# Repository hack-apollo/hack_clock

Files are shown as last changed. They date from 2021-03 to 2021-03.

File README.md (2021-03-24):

HACK LABS MatrixClock : https://www.youtube.com/watch?v=k0h2WS6Prsc&t=33s                                                                                
Author: HACK实验室                                                                                     
YouTube ID: HACK实验室, welcome to subscribe https://www.youtube.com/c/HACK实验室                                                        
HACK_CLOCK is a free download and may be used, modified, evaluated and
distributed without charge provided the user adheres to version three of the GNU
General Public License (GPL) and does not remove the copyright notice or this
text.  The GPL V3 text is available on the gnu.org web site
作者：HACK实验室                                                                                        
B站ID：HACK实验室  欢迎订阅 https://space.bilibili.com/395145107                                                                            
微信公众号：HACK实验室，开源资料唯一发布点，定期分享开源硬件以及有价值的技术文章，欢迎关注.                                                                                                             

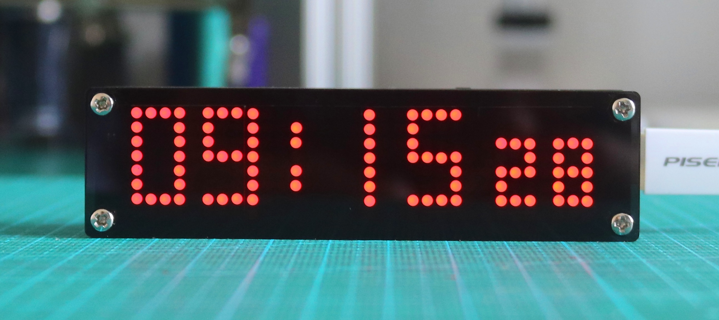
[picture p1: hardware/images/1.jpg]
Image text


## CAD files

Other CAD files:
hardware/滤光板/挡板1.dwg

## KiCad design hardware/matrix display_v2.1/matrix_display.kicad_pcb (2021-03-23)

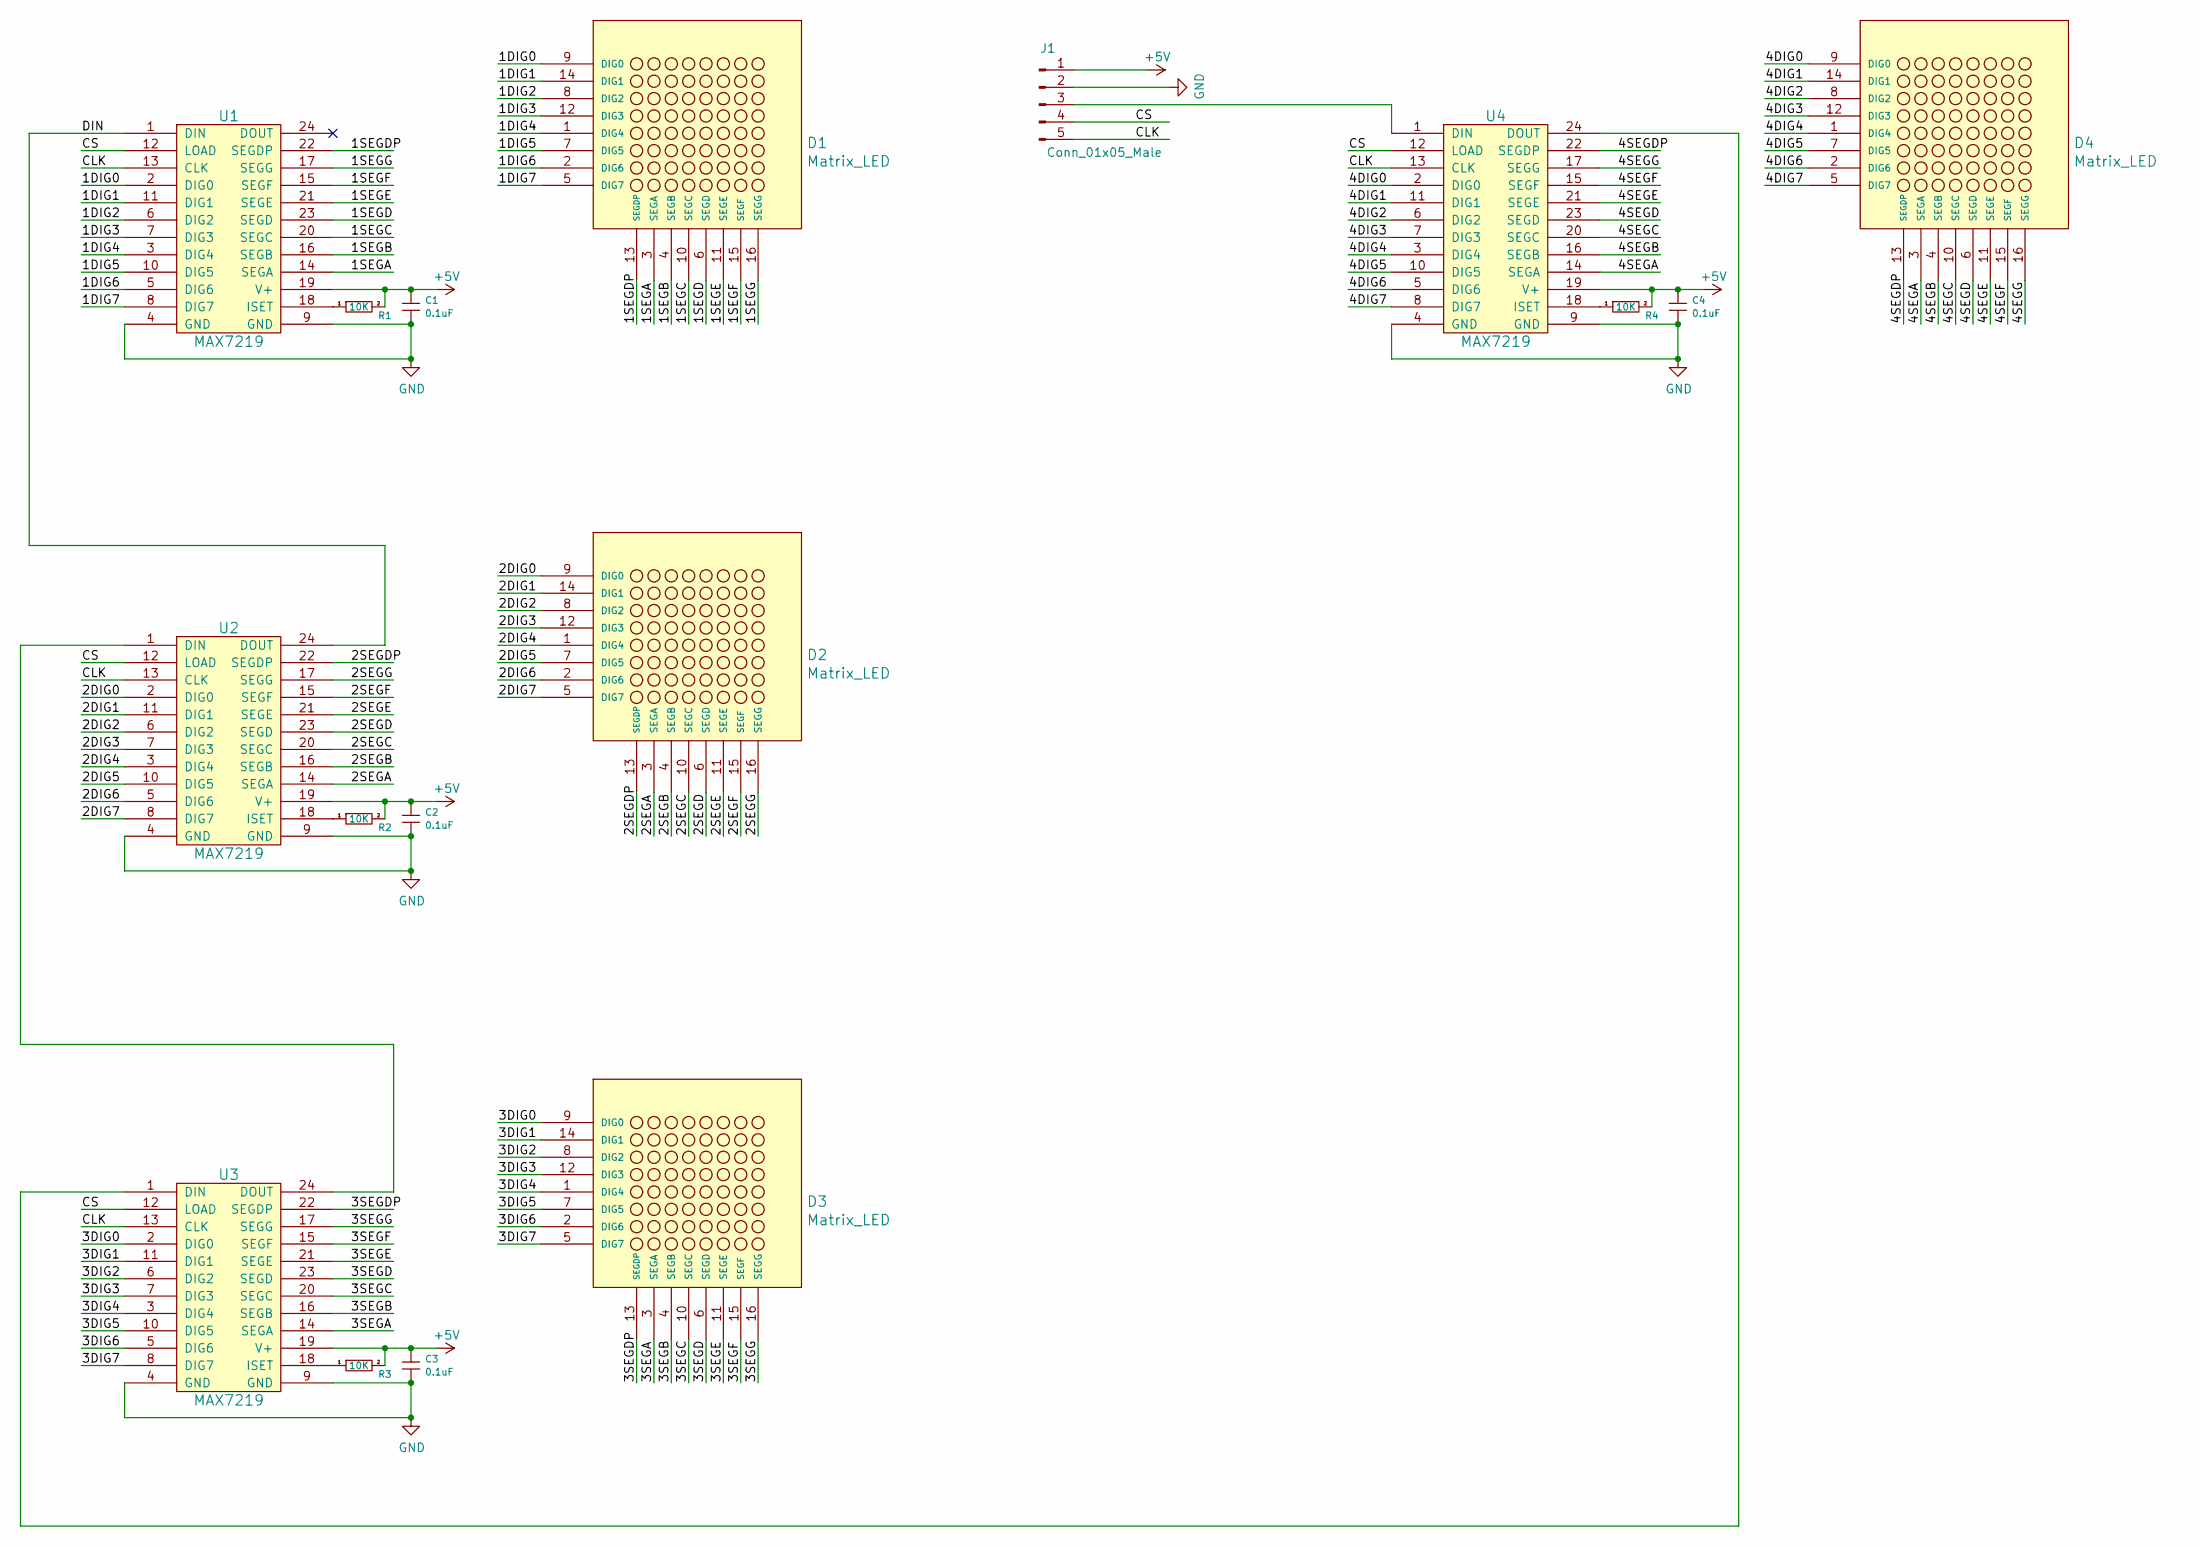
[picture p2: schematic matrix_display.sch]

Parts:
C1, C2, C3, C4: 0.1uF; 0603_C
D1, D2, D3, D4: Matrix_LED
J1: Conn_01x05_Male; PinHeader_1x05_P2.00mm_Vertical
R1, R2, R3, R4: 10K; 0603_R
U1, U2, U3, U4: MAX7219; SOIC-24W_7.5x15.4mm_P1.27mm

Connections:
+5V: C1.1, C2.1, C3.1, C4.1, J1.1, R1.2, R2.2, R3.2, R4.2, U1.19 (V+), U2.19 (V+), U3.19 (V+), U4.19 (V+)
/1DIG0: D1.9 (DIG0), U1.2 (DIG0)
/1DIG1: D1.14 (DIG1), U1.11 (DIG1)
/1DIG2: D1.8 (DIG2), U1.6 (DIG2)
/1DIG3: D1.12 (DIG3), U1.7 (DIG3)
/1DIG4: D1.1 (DIG4), U1.3 (DIG4)
/1DIG5: D1.7 (DIG5), U1.10 (DIG5)
/1DIG6: D1.2 (DIG6), U1.5 (DIG6)
/1DIG7: D1.5 (DIG7), U1.8 (DIG7)
/1SEGA: D1.3 (SEGA), U1.14 (SEGA)
/1SEGB: D1.4 (SEGB), U1.16 (SEGB)
/1SEGC: D1.10 (SEGC), U1.20 (SEGC)
/1SEGD: D1.6 (SEGD), U1.23 (SEGD)
/1SEGDP: D1.13 (SEGDP), U1.22 (SEGDP)
/1SEGE: D1.11 (SEGE), U1.21 (SEGE)
/1SEGF: D1.15 (SEGF), U1.15 (SEGF)
/1SEGG: D1.16 (SEGG), U1.17 (SEGG)
/2DIG0: D2.9 (DIG0), U2.2 (DIG0)
/2DIG1: D2.14 (DIG1), U2.11 (DIG1)
/2DIG2: D2.8 (DIG2), U2.6 (DIG2)
/2DIG3: D2.12 (DIG3), U2.7 (DIG3)
/2DIG4: D2.1 (DIG4), U2.3 (DIG4)
/2DIG5: D2.7 (DIG5), U2.10 (DIG5)
/2DIG6: D2.2 (DIG6), U2.5 (DIG6)
/2DIG7: D2.5 (DIG7), U2.8 (DIG7)
/2SEGA: D2.3 (SEGA), U2.14 (SEGA)
/2SEGB: D2.4 (SEGB), U2.16 (SEGB)
/2SEGC: D2.10 (SEGC), U2.20 (SEGC)
/2SEGD: D2.6 (SEGD), U2.23 (SEGD)
/2SEGDP: D2.13 (SEGDP), U2.22 (SEGDP)
/2SEGE: D2.11 (SEGE), U2.21 (SEGE)
/2SEGF: D2.15 (SEGF), U2.15 (SEGF)
/2SEGG: D2.16 (SEGG), U2.17 (SEGG)
/3DIG0: D3.9 (DIG0), U3.2 (DIG0)
/3DIG1: D3.14 (DIG1), U3.11 (DIG1)
/3DIG2: D3.8 (DIG2), U3.6 (DIG2)
/3DIG3: D3.12 (DIG3), U3.7 (DIG3)
/3DIG4: D3.1 (DIG4), U3.3 (DIG4)
/3DIG5: D3.7 (DIG5), U3.10 (DIG5)
/3DIG6: D3.2 (DIG6), U3.5 (DIG6)
/3DIG7: D3.5 (DIG7), U3.8 (DIG7)
/3SEGA: D3.3 (SEGA), U3.14 (SEGA)
/3SEGB: D3.4 (SEGB), U3.16 (SEGB)
/3SEGC: D3.10 (SEGC), U3.20 (SEGC)
/3SEGD: D3.6 (SEGD), U3.23 (SEGD)
/3SEGDP: D3.13 (SEGDP), U3.22 (SEGDP)
/3SEGE: D3.11 (SEGE), U3.21 (SEGE)
/3SEGF: D3.15 (SEGF), U3.15 (SEGF)
/3SEGG: D3.16 (SEGG), U3.17 (SEGG)
/4DIG0: D4.9 (DIG0), U4.2 (DIG0)
/4DIG1: D4.14 (DIG1), U4.11 (DIG1)
/4DIG2: D4.8 (DIG2), U4.6 (DIG2)
/4DIG3: D4.12 (DIG3), U4.7 (DIG3)
/4DIG4: D4.1 (DIG4), U4.3 (DIG4)
/4DIG5: D4.7 (DIG5), U4.10 (DIG5)
/4DIG6: D4.2 (DIG6), U4.5 (DIG6)
/4DIG7: D4.5 (DIG7), U4.8 (DIG7)
/4SEGA: D4.3 (SEGA), U4.14 (SEGA)
/4SEGB: D4.4 (SEGB), U4.16 (SEGB)
/4SEGC: D4.10 (SEGC), U4.20 (SEGC)
/4SEGD: D4.6 (SEGD), U4.23 (SEGD)
/4SEGDP: D4.13 (SEGDP), U4.22 (SEGDP)
/4SEGE: D4.11 (SEGE), U4.21 (SEGE)
/4SEGF: D4.15 (SEGF), U4.15 (SEGF)
/4SEGG: D4.16 (SEGG), U4.17 (SEGG)
/CLK: J1.5, U1.13 (CLK), U2.13 (CLK), U3.13 (CLK), U4.13 (CLK)
/CS: J1.4, U1.12 (LOAD), U2.12 (LOAD), U3.12 (LOAD), U4.12 (LOAD)
/DIN: U1.1 (DIN), U2.24 (DOUT)
GND: C1.2, C2.2, C3.2, C4.2, J1.2, U1.4 (GND), U1.9 (GND), U2.4 (GND), U2.9 (GND), U3.4 (GND), U3.9 (GND), U4.4 (GND), U4.9 (GND)
unnamed: J1.3, U4.1 (DIN)
unnamed: R1.1, U1.18 (ISET)
unnamed: R2.1, U2.18 (ISET)
unnamed: R3.1, U3.18 (ISET)
unnamed: R4.1, U4.18 (ISET)
unnamed: U2.1 (DIN), U3.24 (DOUT)
unnamed: U3.1 (DIN), U4.24 (DOUT)

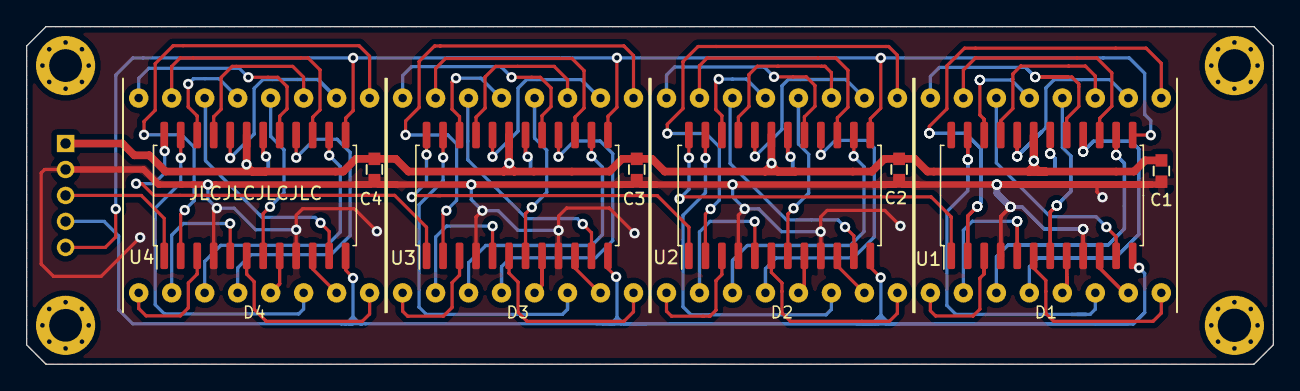
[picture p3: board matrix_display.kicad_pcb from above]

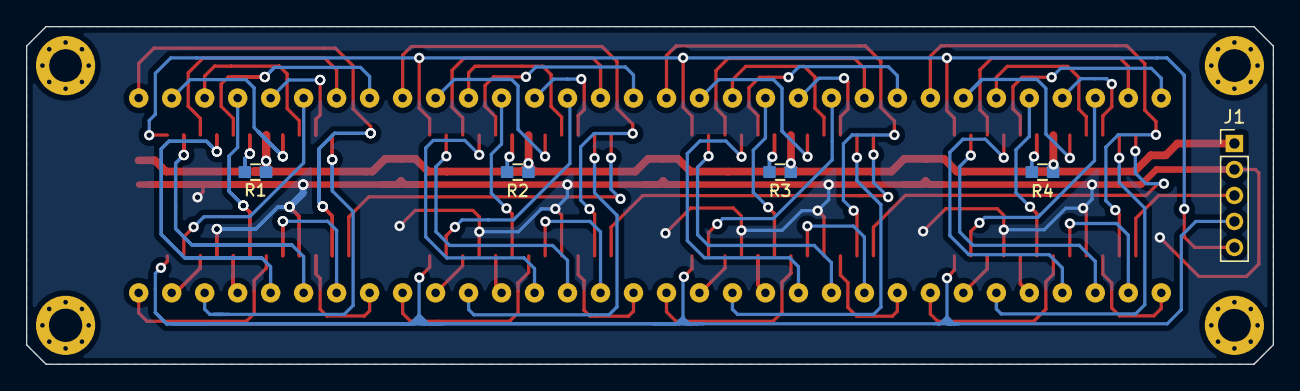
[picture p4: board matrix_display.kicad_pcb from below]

Board: 2 copper layers, 96.0 x 26.0 mm, 17 parts (5 on the bottom side), 76 nets.

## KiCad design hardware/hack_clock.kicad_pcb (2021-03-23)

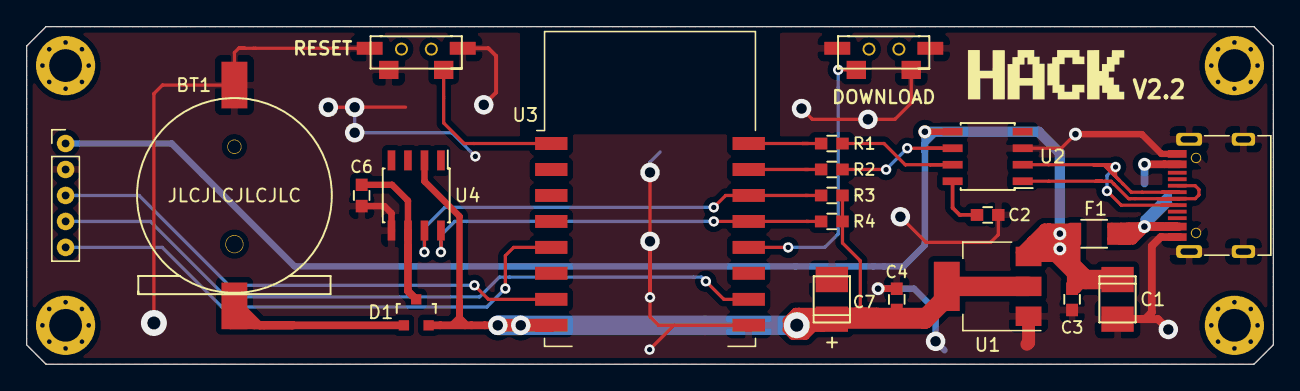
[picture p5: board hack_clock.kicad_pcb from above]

Board: 2 copper layers, 96.0 x 26.0 mm, 23 parts (1 on the bottom side), 20 nets.

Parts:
BT1: BATTERY(M); CR1220-SMD
C1, C7: 100uF; TantalC_SizeT_3528
C2, C6: 0.1uF; 0603_C
C3, C4: 1uF; 0603_C
D1: BAT54C; SOT-23
F1: FUSE*; F_1206
J1: Conn_01x05_Male; PinHeader_1x05_P2.00mm_Vertical
J2: Jack-DC; BarrelJack_DCDC-SMT
P3: USB_C_Plug_USB2.0; USB-Type-C-NEW
P665: CON_1; CON1
R1, R2: RES(M); 0603_R
R3, R4: 10K; 0603_R
SW1, SW2: switch; SWITCH_PUSH
U1: AMS1117; SOT-223-3_TabPin2
U2: CH340N; SOP-8
U3: ESP-12; ESP-12S
U4: DS3231MZ+; SOP-8

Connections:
+3V3: C4.2, C7.1, D1.2, R3.2, R4.2, U1.2, U3.8, U4.2
+5V: C1.1, C3.2, F1.2, J1.1, U1.3, U2.5
/CLK: J1.5, U3.5
/CS: J1.4, U3.16
/DIN: J1.3, U3.7
/RXD: R1.2, U3.22
/SCL: R4.1, U3.19, U4.8
/SDA: R3.1, U3.20, U4.7
/TXD: R2.2, U3.21
/USB_D+: P3.A6, U2.1
/USB_D-: P3.A7, U2.2
GND: BT1.2, C1.2, C2.1, C3.1, C4.1, C6.1, C7.2, J1.2, J2.2, P3.A1, P3.S1, SW1.1, SW2.1, U1.1, U2.3, U3.15, U4.5
unnamed: BT1.1, D1.1
unnamed: C2.2, U2.8
unnamed: C6.2, D1.3, U4.6
unnamed: F1.1, J2.1, P3.A4
unnamed: R1.1, U2.7
unnamed: R2.1, U2.6
unnamed: SW1.2, U3.1
unnamed: SW2.2, U3.18

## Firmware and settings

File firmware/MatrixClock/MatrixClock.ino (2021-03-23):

/*********************************************************************************************************
  HACK LABS MatrixClock                                                                                 
  ********************************************************************************************************
  Author: HACK实验室                                                                                     
  YouTube ID: HACK实验室, welcome to subscribe：https://www.youtube.com/channel/UCxFY1FcIYK9d7riTvIh6eiA                                                          
  Version 2.0 
  HACK_CLOCK is a free download and may be used, modified, evaluated and
  distributed without charge provided the user adheres to version hree of the GNU
  General Public License (GPL) and does not remove the copyright notice or this
  text.  The GPL V3 text is available on the gnu.org web site
  作者：HACK实验室                                                                                        
  B站ID：HACK实验室  欢迎订阅：https://space.bilibili.com/395145107                                                                             
  微信公众号：HACK实验室，开源资料唯一发布点，定期分享开源硬件以及有价值的技术文章，欢迎关注.                        
  Version 2.0                                                                                           
  HACK_CLOCK是一个完全开源的硬件项目，允许用户免费下载使用，但需遵守GPL V3开源协议，协议文本可在gnu.org网站上获得.    
*********************************************************************************************************/

#include <SPI.h>
#include <Ticker.h>
#include <ESP8266WiFi.h>
#include <WiFiClient.h>
#include <WiFiUdp.h>
#include <Wire.h>
#include <time.h>

#define SDA        5      // Pin sda (I2C)
#define SCL        4      // Pin scl (I2C)
#define CS         15     // Pin cs  (SPI)
#define anzMAX     4     


char ssid[] = "";                    // your network SSID (name)
char pass[] = "";                    // your network password

unsigned short maxPosX = anzMAX * 8 - 1;            
unsigned short LEDarr[anzMAX][8];                   
unsigned short helpArrMAX[anzMAX * 8];              
unsigned short helpArrPos[anzMAX * 8];              
unsigned int z_PosX = 0;                            
unsigned int d_PosX = 0;                            
bool f_tckr1s = false;
bool f_tckr50ms = false;
unsigned long epoch = 0;
unsigned int localPort = 2390;                      // local port to listen for UDP packets
const char* ntpServerName = "time1.aliyun.com";
const int NTP_PACKET_SIZE = 48;                     // NTP time stamp is in the first 48 bytes of the message
byte packetBuffer[NTP_PACKET_SIZE];                 // buffer to hold incoming and outgoing packets
IPAddress timeServerIP;                            
tm *tt, ttm;


const unsigned char DS3231_ADDRESS = 0x68;
const unsigned char secondREG = 0x00;
const unsigned char minuteREG = 0x01;
const unsigned char hourREG = 0x02;
const unsigned char WTREG = 0x03;                   //weekday
const unsigned char dateREG = 0x04;
const unsigned char monthREG = 0x05;
const unsigned char yearREG = 0x06;
const unsigned char alarm_min1secREG = 0x07;
const unsigned char alarm_min1minREG = 0x08;
const unsigned char alarm_min1hrREG = 0x09;
const unsigned char alarm_min1dateREG = 0x0A;
const unsigned char alarm_min2minREG = 0x0B;
const unsigned char alarm_min2hrREG = 0x0C;
const unsigned char alarm_min2dateREG = 0x0D;
const unsigned char controlREG = 0x0E;
const unsigned char statusREG = 0x0F;
const unsigned char ageoffsetREG = 0x10;
const unsigned char tempMSBREG = 0x11;
const unsigned char tempLSBREG = 0x12;
const unsigned char _24_hour_format = 0;
const unsigned char _12_hour_format = 1;
const unsigned char AM = 0;
const unsigned char PM = 1;

struct DateTime {
    unsigned short sek1, sek2, sek12, min1, min2, min12, std1, std2, std12;
    unsigned short tag1, tag2, tag12, mon1, mon2, mon12, jahr1, jahr2, jahr12, WT;
} MEZ;


// The object for the Ticker
Ticker tckr;
// A UDP instance to let us send and receive packets over UDP
WiFiUDP udp;


//months
char M_arr[12][5] = { { ' ', 'J', 'A', 'N', ' ' }, { ' ', 'F', 'E', 'B', ' ' },
        { ' ', 'M', 'A', 'R', ' ' }, { ' ', 'A', 'P', 'R', ' ' }, { ' ', 'M', 'A',
                'Y', ' ' }, { ' ', 'J', 'U', 'N', ' ' }, { ' ', 'J', 'U', 'L', ' ' }, {
                ' ', 'A', 'U', 'G', ' ' }, { ' ', 'S', 'E', 'P', ' ' }, { ' ', 'O', 'C',
                'T', ' ' }, { ' ', 'N', 'O', 'V', ' ' }, { ' ', 'D', 'E', 'C', ' ' } };
//days
char WT_arr[7][4] = { { 'S', 'U', 'N', ' ' }, { 'M', 'O', 'N', ' ' }, { 'T', 'U', 'E', ' ' }, {
        'W', 'E', 'D', ' ' }, { 'T', 'H', 'U', ' ' }, { 'F', 'R', 'I', ' ' }, { 'S', 'A', 'T', ' ' } };

// Zeichensatz 5x8 in einer 8x8 Matrix, 0,0 ist rechts oben
unsigned short const font1[96][9] = { { 0x07, 0x00, 0x00, 0x00, 0x00, 0x00,
        0x00, 0x00, 0x00 },   // 0x20, Space
        { 0x07, 0x04, 0x04, 0x04, 0x04, 0x04, 0x00, 0x04, 0x00 },   // 0x21, !
        { 0x07, 0x09, 0x09, 0x12, 0x00, 0x00, 0x00, 0x00, 0x00 },   // 0x22, "
        { 0x07, 0x0a, 0x0a, 0x1f, 0x0a, 0x1f, 0x0a, 0x0a, 0x00 },   // 0x23, #
        { 0x07, 0x04, 0x0f, 0x14, 0x0e, 0x05, 0x1e, 0x04, 0x00 },   // 0x24, $
        { 0x07, 0x19, 0x19, 0x02, 0x04, 0x08, 0x13, 0x13, 0x00 },   // 0x25, %
        { 0x07, 0x04, 0x0a, 0x0a, 0x0a, 0x15, 0x12, 0x0d, 0x00 },   // 0x26, &
        { 0x07, 0x04, 0x04, 0x08, 0x00, 0x00, 0x00, 0x00, 0x00 },   // 0x27, '
        { 0x07, 0x02, 0x04, 0x08, 0x08, 0x08, 0x04, 0x02, 0x00 },   // 0x28, (
        { 0x07, 0x08, 0x04, 0x02, 0x02, 0x02, 0x04, 0x08, 0x00 },   // 0x29, )
        { 0x07, 0x04, 0x15, 0x0e, 0x1f, 0x0e, 0x15, 0x04, 0x00 },   // 0x2a, *
        { 0x07, 0x00, 0x04, 0x04, 0x1f, 0x04, 0x04, 0x00, 0x00 },   // 0x2b, +
        { 0x04, 0x00, 0x00, 0x00, 0x00, 0x00, 0x01, 0x01, 0x02 },   // 0x2c, ,
        { 0x07, 0x00, 0x00, 0x00, 0x1f, 0x00, 0x00, 0x00, 0x00 },   // 0x2d, -
        { 0x04, 0x00, 0x00, 0x00, 0x00, 0x00, 0x03, 0x03, 0x00 },   // 0x2e, .
        { 0x07, 0x01, 0x01, 0x02, 0x04, 0x08, 0x10, 0x10, 0x00 },   // 0x2f, /
        { 0x07, 0x0F, 0x09, 0x09, 0x09, 0x09, 0x09, 0x0F, 0x00 },   // 0x30, 0
        { 0x07, 0x02, 0x02, 0x02, 0x02, 0x02, 0x02, 0x02, 0x00 },   // 0x31, 1
        { 0x07, 0x0F, 0x01, 0x01, 0x0F, 0x08, 0x08, 0x0F, 0x00 },   // 0x32, 2
        { 0x07, 0x0F, 0x01, 0x01, 0x0F, 0x01, 0x01, 0x0F, 0x00 },   // 0x33, 3
        { 0x07, 0x09, 0x09, 0x09, 0x0F, 0x01, 0x01, 0x01, 0x00 },   // 0x34, 4
        { 0x07, 0x0F, 0x08, 0x08, 0x0F, 0x01, 0x01, 0x0F, 0x00 },   // 0x35, 5
        { 0x07, 0x0F, 0x08, 0x08, 0x0F, 0x09, 0x09, 0x0F, 0x00 },   // 0x36, 6
        { 0x07, 0x0F, 0x01, 0x01, 0x01, 0x01, 0x01, 0x01, 0x00 },   // 0x37, 7
        { 0x07, 0x0F, 0x09, 0x09, 0x0F, 0x09, 0x09, 0x0F, 0x00 },   // 0x38, 8
        { 0x07, 0x0F, 0x09, 0x09, 0x0F, 0x01, 0x01, 0x0F, 0x00 },   // 0x39, 9
        { 0x04, 0x00, 0x01, 0x01, 0x00, 0x01, 0x01, 0x00, 0x00 },   // 0x3a, :
        { 0x07, 0x00, 0x0c, 0x0c, 0x00, 0x0c, 0x04, 0x08, 0x00 },   // 0x3b, ;
        { 0x07, 0x02, 0x04, 0x08, 0x10, 0x08, 0x04, 0x02, 0x00 },   // 0x3c, <
        { 0x04, 0x00, 0x00, 0x00, 0x00, 0x00, 0x00, 0x00, 0x00 },   // 0x3d, =
        { 0x07, 0x08, 0x04, 0x02, 0x01, 0x02, 0x04, 0x08, 0x00 },   // 0x3e, >
        { 0x07, 0x0e, 0x11, 0x01, 0x02, 0x04, 0x00, 0x04, 0x00 },   // 0x3f, ?
        { 0x07, 0x0e, 0x11, 0x17, 0x15, 0x17, 0x10, 0x0f, 0x00 },   // 0x40, @
        { 0x07, 0x04, 0x0a, 0x11, 0x11, 0x1f, 0x11, 0x11, 0x00 },   // 0x41, A
        { 0x07, 0x1e, 0x11, 0x11, 0x1e, 0x11, 0x11, 0x1e, 0x00 },   // 0x42, B
        { 0x07, 0x0e, 0x11, 0x10, 0x10, 0x10, 0x11, 0x0e, 0x00 },   // 0x43, C
        { 0x07, 0x1E, 0x11, 0x11, 0x11, 0x11, 0x11, 0x1E, 0x00 },   // 0x44, D
        { 0x07, 0x1f, 0x10, 0x10, 0x1c, 0x10, 0x10, 0x1f, 0x00 },   // 0x45, E
        { 0x07, 0x1f, 0x10, 0x10, 0x1f, 0x10, 0x10, 0x10, 0x00 },   // 0x46, F
        { 0x07, 0x0e, 0x11, 0x10, 0x10, 0x13, 0x11, 0x0f, 0x00 },   // 0x37, G
        { 0x07, 0x11, 0x11, 0x11, 0x1f, 0x11, 0x11, 0x11, 0x00 },   // 0x48, H
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
        { 0x07, 0x1f, 0x1f, 0x1f, 0x1f, 0x1f, 0x1f, 0x1f, 0x00 }    // 0x7f, DEL
};

// Zeichensatz 5x8 in einer 8x8 Matrix, 0,0 ist rechts oben
unsigned short const font2[96][9] = { { 0x07, 0x00, 0x00, 0x00, 0x00, 0x00,
        0x00, 0x00, 0x00 },   // 0x20, Space
        { 0x07, 0x04, 0x04, 0x04, 0x04, 0x04, 0x00, 0x04, 0x00 },   // 0x21, !
        { 0x07, 0x09, 0x09, 0x12, 0x00, 0x00, 0x00, 0x00, 0x00 },   // 0x22, "
        { 0x07, 0x0a, 0x0a, 0x1f, 0x0a, 0x1f, 0x0a, 0x0a, 0x00 },   // 0x23, #
        { 0x07, 0x04, 0x0f, 0x14, 0x0e, 0x05, 0x1e, 0x04, 0x00 },   // 0x24, $
        { 0x07, 0x19, 0x19, 0x02, 0x04, 0x08, 0x13, 0x13, 0x00 },   // 0x25, %
        { 0x07, 0x04, 0x0a, 0x0a, 0x0a, 0x15, 0x12, 0x0d, 0x00 },   // 0x26, &
        { 0x07, 0x04, 0x04, 0x08, 0x00, 0x00, 0x00, 0x00, 0x00 },   // 0x27, '
        { 0x07, 0x02, 0x04, 0x08, 0x08, 0x08, 0x04, 0x02, 0x00 },   // 0x28, (
        { 0x07, 0x08, 0x04, 0x02, 0x02, 0x02, 0x04, 0x08, 0x00 },   // 0x29, )
        { 0x07, 0x04, 0x15, 0x0e, 0x1f, 0x0e, 0x15, 0x04, 0x00 },   // 0x2a, *
        { 0x07, 0x00, 0x04, 0x04, 0x1f, 0x04, 0x04, 0x00, 0x00 },   // 0x2b, +
        { 0x04, 0x00, 0x00, 0x00, 0x00, 0x00, 0x01, 0x01, 0x02 },   // 0x2c, ,
        { 0x07, 0x00, 0x00, 0x00, 0x1f, 0x00, 0x00, 0x00, 0x00 },   // 0x2d, -
        { 0x04, 0x00, 0x00, 0x00, 0x00, 0x00, 0x03, 0x03, 0x00 },   // 0x2e, .
        { 0x07, 0x01, 0x01, 0x02, 0x04, 0x08, 0x10, 0x10, 0x00 },   // 0x2f, /
        { 0x07, 0x00, 0x00, 0x07, 0x05, 0x05, 0x05, 0x07, 0x00 },   // 0x30, 0
        { 0x07, 0x00, 0x00, 0x02, 0x02, 0x02, 0x02, 0x02, 0x00 },   // 0x31, 1
        { 0x07, 0x00, 0x00, 0x07, 0x01, 0x07, 0x04, 0x07, 0x00 },   // 0x32, 2
        { 0x07, 0x00, 0x00, 0x07, 0x01, 0x07, 0x01, 0x07, 0x00 },   // 0x33, 3
        { 0x07, 0x00, 0x00, 0x05, 0x05, 0x07, 0x01, 0x01, 0x00 },   // 0x34, 4
        { 0x07, 0x00, 0x00, 0x07, 0x04, 0x07, 0x01, 0x07, 0x00 },   // 0x35, 5
        { 0x07, 0x00, 0x00, 0x07, 0x04, 0x07, 0x05, 0x07, 0x00 },   // 0x36, 6
        { 0x07, 0x00, 0x00, 0x07, 0x01, 0x01, 0x01, 0x01, 0x00 },   // 0x37, 7
        { 0x07, 0x00, 0x00, 0x07, 0x05, 0x07, 0x05, 0x07, 0x00 },   // 0x38, 8
        { 0x07, 0x00, 0x00, 0x07, 0x05, 0x07, 0x01, 0x07, 0x00 },   // 0x39, 9
        { 0x04, 0x00, 0x03, 0x03, 0x00, 0x03, 0x03, 0x00, 0x00 },   // 0x3a, :
        { 0x07, 0x00, 0x0c, 0x0c, 0x00, 0x0c, 0x04, 0x08, 0x00 },   // 0x3b, ;
        { 0x07, 0x02, 0x04, 0x08, 0x10, 0x08, 0x04, 0x02, 0x00 },   // 0x3c, <
        { 0x04, 0x00, 0x00, 0x00, 0x00, 0x00, 0x00, 0x00, 0x00 },   // 0x3d, =
        { 0x07, 0x08, 0x04, 0x02, 0x01, 0x02, 0x04, 0x08, 0x00 },   // 0x3e, >
        { 0x07, 0x0e, 0x11, 0x01, 0x02, 0x04, 0x00, 0x04, 0x00 },   // 0x3f, ?
        { 0x07, 0x0e, 0x11, 0x17, 0x15, 0x17, 0x10, 0x0f, 0x00 },   // 0x40, @
        { 0x07, 0x04, 0x0a, 0x11, 0x11, 0x1f, 0x11, 0x11, 0x00 },   // 0x41, A
        { 0x07, 0x1e, 0x11, 0x11, 0x1e, 0x11, 0x11, 0x1e, 0x00 },   // 0x42, B
        { 0x07, 0x0e, 0x11, 0x10, 0x10, 0x10, 0x11, 0x0e, 0x00 },   // 0x43, C
        { 0x07, 0x1E, 0x11, 0x11, 0x11, 0x11, 0x11, 0x1E, 0x00 },   // 0x44, D
        { 0x07, 0x1f, 0x10, 0x10, 0x1c, 0x10, 0x10, 0x1f, 0x00 },   // 0x45, E
        { 0x07, 0x1f, 0x10, 0x10, 0x1f, 0x10, 0x10, 0x10, 0x00 },   // 0x46, F
        { 0x07, 0x0e, 0x11, 0x10, 0x10, 0x13, 0x11, 0x0f, 0x00 },   // 0x37, G
        { 0x07, 0x11, 0x11, 0x11, 0x1f, 0x11, 0x11, 0x11, 0x00 },   // 0x48, H
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
        { 0x07, 0x1f, 0x1f, 0x1f, 0x1f, 0x1f, 0x1f, 0x1f, 0x00 }    // 0x7f, DEL
};
//**************************************************************************************************
bool autoConfig()
{
    WiFi.begin();                    // 默认连接保存的WIFI

    for (int i = 0; i < 10; i++)
    {
       char2Arr('W', 28, 0);
       char2Arr('i', 22, 0);
       char2Arr('-', 18, 0);
       char2Arr('F', 12, 0);
       char2Arr('i', 6, 0);

       refresh_display(); 
       
       if (WiFi.status() == WL_CONNECTED)
       {
          Serial.println("AutoConfig Success");
          Serial.printf("SSID:%s\r\n", WiFi.SSID().c_str());
          Serial.printf("PSW:%s\r\n", WiFi.psk().c_str());
          clear_Display();
          char2Arr('O', 25, 0);
          char2Arr('K', 19, 0);
          char2Arr('!', 12, 0);
          char2Arr('!', 6, 0);
          refresh_display(); 

          Serial.println("WiFi connected");
          Serial.println(WiFi.localIP());
          Serial.println("Starting UDP");
          udp.begin(localPort);
          Serial.print("Local port: ");
          Serial.println(udp.localPort());
          return true;
       }
       else{
          Serial.print("AutoConfig Waiting......");
          Serial.println(WiFi.status());
          delay(1000);
       }
    }
    clear_Display();
    char2Arr('E', 25, 0);
    char2Arr('r', 19, 0);
    char2Arr('r', 12, 0);
    char2Arr('!', 6, 0);
    refresh_display(); 
    delay(1000);
    Serial.println("AutoConfig Faild!" );
    return false;
}
//**************************************************************************************************
void smartConfig()
{
    int i = 0;
  
    WiFi.mode(WIFI_STA);
    Serial.println("\r\nWait for Smartconfig");
    WiFi.beginSmartConfig();
    for (i = 0; i < 30; i++)
    {
       Serial.print(".");
       if(WiFi.smartConfigDone())
       {
          clear_Display();
          char2Arr('O', 25, 0);
          char2Arr('K', 19, 0);
          char2Arr('!', 12, 0);
          char2Arr('!', 6, 0);
          refresh_display(); 
          Serial.println("SmartConfig Success");
          Serial.printf("SSID:%s\r\n", WiFi.SSID().c_str());
          Serial.printf("PSW:%s\r\n", WiFi.psk().c_str());
          WiFi.setAutoConnect(true);  // 设置自动连接
          
          Serial.println("WiFi connected");
          Serial.println(WiFi.localIP());
          Serial.println("Starting UDP");
          udp.begin(localPort);
          Serial.print("Local port: ");
          Serial.println(udp.localPort());
          delay(1000); 
          ESP.restart();
          break;
       }
       clear_Display();
       char2Arr('S', 29, 0);
       char2Arr('-', 23, -1);
       char2Arr('c', 17, 0);
       char2Arr('o', 12, 0);
       char2Arr('n', 6, 0);
       refresh_display(); 
       delay(1000);
    }
    if (i > 28)
    {
       clear_Display();
       char2Arr('R', 25, 0);
       char2Arr('T', 19, 0);
       char2Arr('C', 12, 0);
       char2Arr('!', 6, 0);
       refresh_display(); 
       delay(1000);
       Serial.println("SmartConfig Faild!" );
       Serial.println("Clock use RTC!" );
    }
}
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
void loop() {
    //Add your repeated code here
    unsigned int sek1 = 0, sek2 = 0, min1 = 0, min2 = 0, std1 = 0, std2 = 0;
    unsigned int sek11 = 0, sek12 = 0, sek21 = 0, sek22 = 0;
    unsigned int min11 = 0, min12 = 0, min21 = 0, min22 = 0;
    unsigned int std11 = 0, std12 = 0, std21 = 0, std22 = 0;
    signed int x = 0; //x1,x2;
    signed int y = 0, y1 = 0, y2 = 0, y3=0;
    bool updown = false;
    unsigned int sc1 = 0, sc2 = 0, sc3 = 0, sc4 = 0, sc5 = 0, sc6 = 0;
    bool f_scrollend_y = false;
    unsigned int f_scroll_x = false;

    z_PosX = maxPosX;
    d_PosX = -8;
    //  x=0; x1=0; x2=0;

    refresh_display();
    updown = true;
    if (updown == false) {
        y2 = -9;
        y1 = 8;
    }
    if (updown == true) { //scroll  up to down
        y2 = 8;
        y1 = -8;
    }
    while (true) {
        yield();
        if ( MEZ.std12==0 && MEZ.min12==20 && MEZ.sek12==0 ) //syncronisize RTC every day 00:20:00
        { 
            clear_Display();
            delay(500);
            ESP.restart();
        }
        if (f_tckr1s == true)        // flag 1sek
        {
            rtc2mez();
            sek1 = MEZ.sek1;
            sek2 = MEZ.sek2;
            min1 = MEZ.min1;
            min2 = MEZ.min2;
            std1 = MEZ.std1;
            std2 = MEZ.std2;
            y = y2;                 //scroll updown
            sc1 = 1;
            sek1++;
            if (sek1 == 10) {
                sc2 = 1;
                sek2++;
                sek1 = 0;
            }
            if (sek2 == 6) {
                min1++;
                sek2 = 0;
                sc3 = 1;
            }
            if (min1 == 10) {
                min2++;
                min1 = 0;
                sc4 = 1;
            }
            if (min2 == 6) {
                std1++;
                min2 = 0;
                sc5 = 1;
            }
            if (std1 == 10) {
                std2++;
                std1 = 0;
                sc6 = 1;
            }
            if ((std2 == 2) && (std1 == 4)) {
                std1 = 0;
                std2 = 0;
                sc6 = 1;
            }

            sek11 = sek12;
            sek12 = sek1;
            sek21 = sek22;
            sek22 = sek2;
            min11 = min12;
            min12 = min1;
            min21 = min22;
            min22 = min2;
            std11 = std12;
            std12 = std1;
            std21 = std22;
            std22 = std2;
            f_tckr1s = false;
            if (MEZ.sek12 == 45)
                f_scroll_x = true;//滚动开关
        } // end 1s
        if (f_tckr50ms == true) {
            f_tckr50ms = false;
            if (f_scroll_x == true) {
                z_PosX++;
                d_PosX++;
                if (d_PosX == 101)
                    z_PosX = 0;
                if (z_PosX == maxPosX) {
                    f_scroll_x = false;
                    d_PosX = -8;
                }
            }
            if (sc1 == 1) {
                if (updown == 1)
                    y--;
                else
                    y++;
               y3 = y;
               if (y3 > 0) {
                y3 = 0;
                }     
               char22Arr(48 + sek12, z_PosX - 27, y3);
               char22Arr(48 + sek11, z_PosX - 27, y + y1);
                if (y == 0) {
                    sc1 = 0;
                    f_scrollend_y = true;
                }
            }
            else
                char22Arr(48 + sek1, z_PosX - 27, 0);

            if (sc2 == 1) {
                char22Arr(48 + sek22, z_PosX - 23, y3);
                char22Arr(48 + sek21, z_PosX - 23, y + y1);
                if (y == 0)
                    sc2 = 0;
            }
            else
              char22Arr(48 + sek2, z_PosX - 23, 0);

            if (sc3 == 1) {
                char2Arr(48 + min12, z_PosX - 18, y);
                char2Arr(48 + min11, z_PosX - 18, y + y1);
                if (y == 0)
                    sc3 = 0;
            }
            else
                char2Arr(48 + min1, z_PosX - 18, 0);

            if (sc4 == 1) {
                char2Arr(48 + min22, z_PosX - 13, y);
                char2Arr(48 + min21, z_PosX - 13, y + y1);
                if (y == 0)
                    sc4 = 0;
            }
            else
                char2Arr(48 + min2, z_PosX - 13, 0);

              char2Arr(':', z_PosX - 10 + x, 0);

            if (sc5 == 1) {
                char2Arr(48 + std12, z_PosX - 4, y);
                char2Arr(48 + std11, z_PosX - 4, y + y1);
                if (y == 0)
                    sc5 = 0;
            }
            else
                char2Arr(48 + std1, z_PosX - 4, 0);

            if (sc6 == 1) {
                char2Arr(48 + std22, z_PosX + 1, y);
                char2Arr(48 + std21, z_PosX + 1, y + y1);
                if (y == 0)
                    sc6 = 0;
            }
            else
                char2Arr(48 + std2, z_PosX + 1, 0);

            char2Arr(' ', d_PosX+5, 0);        //day of the week
            char2Arr(WT_arr[MEZ.WT][0], d_PosX - 1, 0);        //day of the week
            char2Arr(WT_arr[MEZ.WT][1], d_PosX - 7, 0);
            char2Arr(WT_arr[MEZ.WT][2], d_PosX - 13, 0);
            char2Arr(WT_arr[MEZ.WT][3], d_PosX - 19, 0);
            char2Arr(48 + MEZ.tag2, d_PosX - 24, 0);           //day
            char2Arr(48 + MEZ.tag1, d_PosX - 30, 0);
            char2Arr(M_arr[MEZ.mon12 - 1][0], d_PosX - 39, 0); //month
            char2Arr(M_arr[MEZ.mon12 - 1][1], d_PosX - 43, 0);
            char2Arr(M_arr[MEZ.mon12 - 1][2], d_PosX - 49, 0);
            char2Arr(M_arr[MEZ.mon12 - 1][3], d_PosX - 55, 0);
            char2Arr(M_arr[MEZ.mon12 - 1][4], d_PosX - 61, 0);
            char2Arr('2', d_PosX - 68, 0);                     //year
            char2Arr('0', d_PosX - 74, 0);
            char2Arr(48 + MEZ.jahr2, d_PosX - 80, 0);
            char2Arr(48 + MEZ.jahr1, d_PosX - 86, 0);

            refresh_display(); //alle 50ms
            if (f_scrollend_y == true) {
                f_scrollend_y = false;
            }
        } //end 50ms
        if (y == 0) {
            // do something else
        }
    }  //end while(true)
    //this section can not be reached
}

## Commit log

2020-10-15 first push
    [hack_clock-B_Cu.gbl, hack_clock-B_Mask.gbs, hack_clock-B_Paste.gbp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]
2021-03-23 add images
    [hack_clock-B_Cu.gbl, hack_clock-B_Mask.gbs, hack_clock-B_Paste.gbp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]
